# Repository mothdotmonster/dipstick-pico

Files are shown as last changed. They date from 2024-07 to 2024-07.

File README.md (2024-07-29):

# DIPSTICKpico

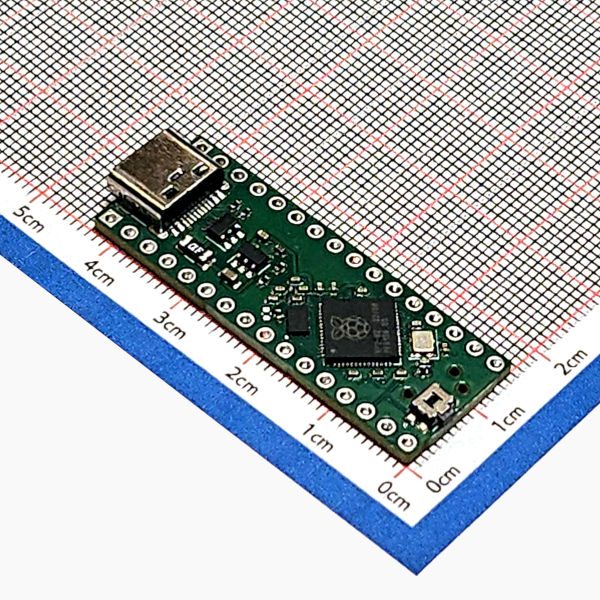
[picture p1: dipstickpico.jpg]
DIPSTICKpico on a familiar grid background


a smaller RP2040 board with USB-C.

[PRODUCTION FILES](https://github.com/mothdotmonster/dipstick-pico/releases/latest)

based off [RPcube](https://github.com/diminDDL/rpcube)  
uses [Paw-Connect](https://github.com/LeoDJ/Paw-Connect)

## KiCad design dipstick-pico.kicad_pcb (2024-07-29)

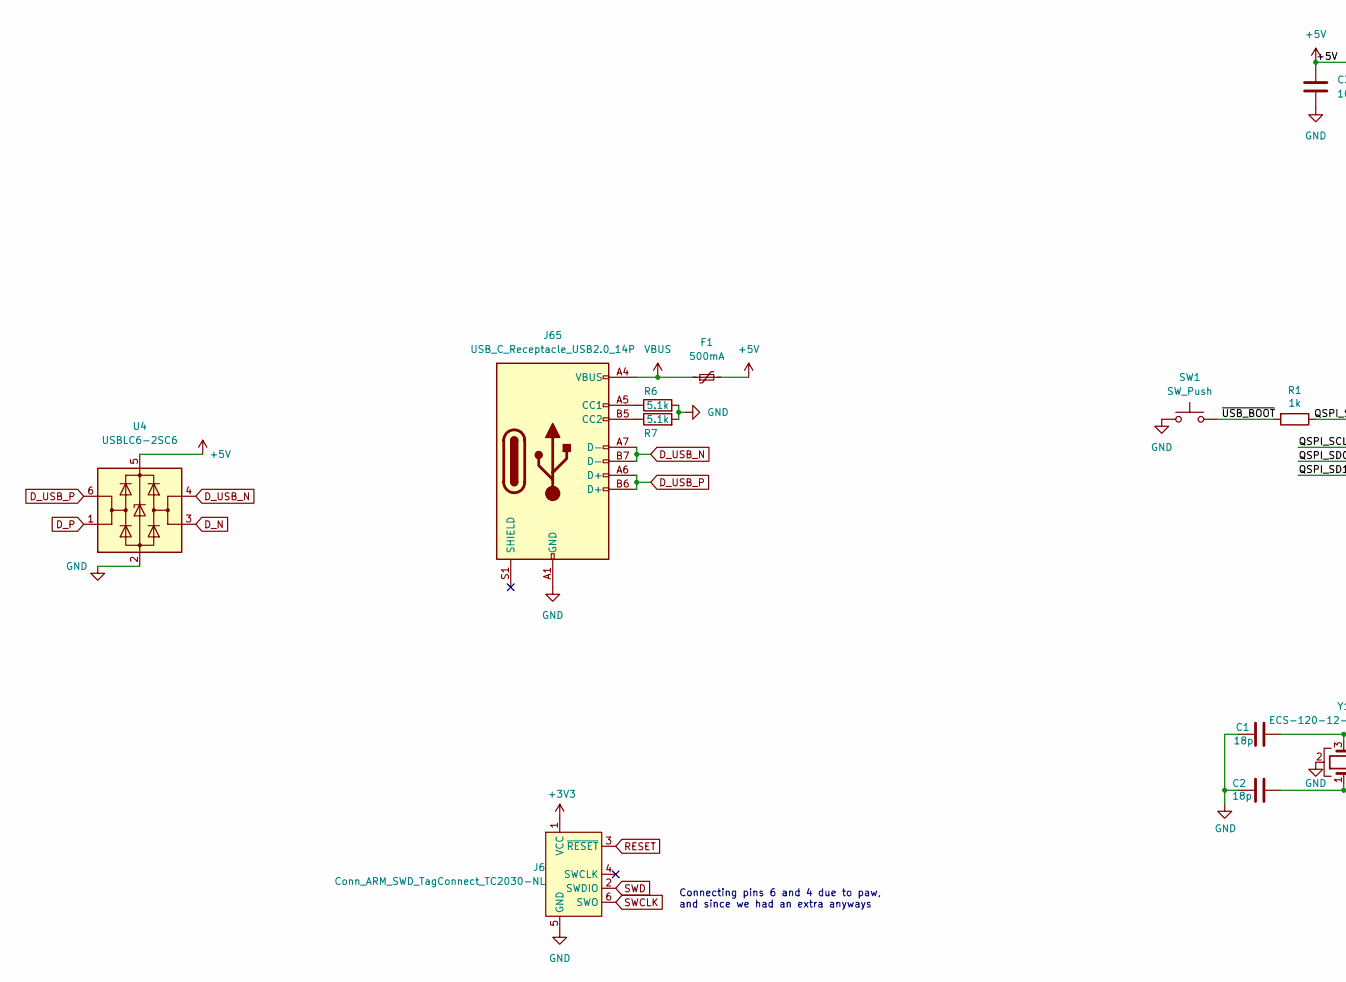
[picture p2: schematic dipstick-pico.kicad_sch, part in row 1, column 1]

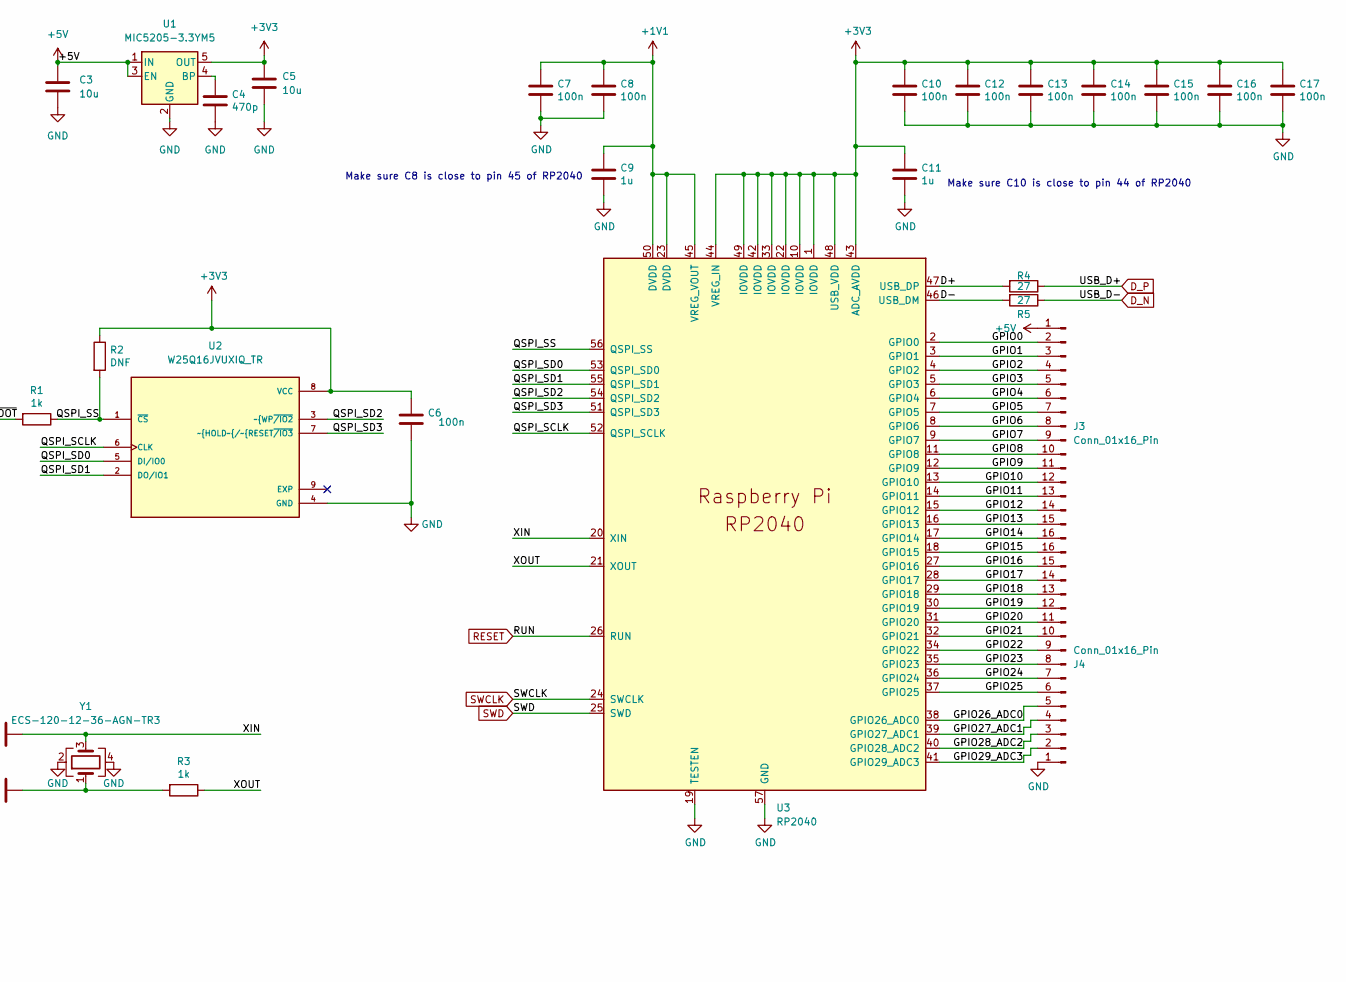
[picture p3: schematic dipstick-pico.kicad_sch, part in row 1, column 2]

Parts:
C1, C2: 18p; C_0402_1005Metric; LCSC C1549
C3: 10u; C_0603_1608Metric; LCSC C19702
C4: 470p; C_0402_1005Metric; LCSC C52923
C5: 10u; C_0402_1005Metric; LCSC C15525
C6, C7, C8, C10, C12, C13, C14, C15, C16, C17: 100n; C_0402_1005Metric; LCSC C1525
C9, C11: 1u; C_0402_1005Metric; LCSC C52923
F1: 500mA; Fuse_1206_3216Metric; LCSC C70076
J3, J4: Conn_01x16_Pin; PinHeader_1x16_P2.54mm_Vertical
J6: Conn_ARM_SWD_TagConnect_TC2030-NL; Tag-Connect_TC2030-IDC-NL_2x03_P1.27mm_Vertical
J65: USB_C_Receptacle_USB2.0_14P; USB_C_Receptacle_HRO_TYPE-C-31-M-12; LCSC C165948
R1, R3: 1k; R_0402_1005Metric; LCSC C11702
R2: DNF; R_0402_1005Metric
R4, R5: 27; R_0402_1005Metric; LCSC C25092
R6, R7: 5.1k; R_0402_1005Metric; LCSC C25905
SW1: SW_Push; SW_EVQ-P7A01P; LCSC C79167
U1: MIC5205-3.3YM5; SOT-23-5; LCSC C37970
U2: W25Q16JVUXIQ_TR; IC_W25Q16JVUXIQ_TR; PARTREV H; LCSC C2843335
U3: RP2040; RP2040-QFN-56; LCSC C2040
U4: USBLC6-2SC6; SOT-23-6; LCSC C2827654
Y1: ECS-120-12-36-AGN-TR3; Crystal_SMD_2520-4Pin_2.5x2.0mm; LCSC C479184

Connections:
+1V1: C7.1, C8.1, C9.1, U3.23 (DVDD), U3.45 (VREG_VOUT), U3.50 (DVDD)
+3V3: C5.1, C6.1, C10.1, C11.1, C12.1, C13.1, C14.1, C15.1, C16.1, C17.1, J6.1 (VCC), R2.1, U1.5 (OUT), U2.8 (VCC), U3.1 (IOVDD), U3.10 (IOVDD), U3.22 (IOVDD), U3.33 (IOVDD), U3.42 (IOVDD), U3.43 (ADC_AVDD), U3.44 (VREG_IN), U3.48 (USB_VDD), U3.49 (IOVDD)
+5V: C3.1, F1.2, J3.1, U1.1 (IN), U1.3 (EN), U4.5 (VBUS)
/D+: R4.2, U3.47 (USB_DP)
/D-: R5.2, U3.46 (USB_DM)
/GPIO0: J3.2, U3.2 (GPIO0)
/GPIO1: J3.3, U3.3 (GPIO1)
/GPIO2: J3.4, U3.4 (GPIO2)
/GPIO3: J3.5, U3.5 (GPIO3)
/GPIO4: J3.6, U3.6 (GPIO4)
/GPIO5: J3.7, U3.7 (GPIO5)
/GPIO6: J3.8, U3.8 (GPIO6)
/GPIO7: J3.9, U3.9 (GPIO7)
/GPIO8: J3.10, U3.11 (GPIO8)
/GPIO9: J3.11, U3.12 (GPIO9)
/GPIO10: J3.12, U3.13 (GPIO10)
/GPIO11: J3.13, U3.14 (GPIO11)
/GPIO12: J3.14, U3.15 (GPIO12)
/GPIO13: J3.15, U3.16 (GPIO13)
/GPIO14: J3.16, U3.17 (GPIO14)
/GPIO15: J4.16, U3.18 (GPIO15)
/GPIO16: J4.15, U3.27 (GPIO16)
/GPIO17: J4.14, U3.28 (GPIO17)
/GPIO18: J4.13, U3.29 (GPIO18)
/GPIO19: J4.12, U3.30 (GPIO19)
/GPIO20: J4.11, U3.31 (GPIO20)
/GPIO21: J4.10, U3.32 (GPIO21)
/GPIO22: J4.9, U3.34 (GPIO22)
/GPIO23: J4.8, U3.35 (GPIO23)
/GPIO24: J4.7, U3.36 (GPIO24)
/GPIO25: J4.6, U3.37 (GPIO25)
/GPIO26_ADC0: J4.5, U3.38 (GPIO26_ADC0)
/GPIO27_ADC1: J4.4, U3.39 (GPIO27_ADC1)
/GPIO28_ADC2: J4.3, U3.40 (GPIO28_ADC2)
/GPIO29_ADC3: J4.2, U3.41 (GPIO29_ADC3)
/QSPI_SCLK: U2.6 (CLK), U3.52 (QSPI_SCLK)
/QSPI_SD0: U2.5 (DI/IO0), U3.53 (QSPI_SD0)
/QSPI_SD1: U2.2 (DO/IO1), U3.55 (QSPI_SD1)
/QSPI_SD2: U2.3 (~WP~{/IO2), U3.54 (QSPI_SD2)
/QSPI_SD3: U2.7 (~HOLD~{/~{RESET~{/IO3), U3.51 (QSPI_SD3)
/QSPI_SS: R1.1, R2.2, U2.1 (~CS), U3.56 (QSPI_SS)
/XIN: C1.1, U3.20 (XIN), Y1.3
/XOUT: R3.1, U3.21 (XOUT)
/~USB_BOOT: R1.2, SW1.1_1, SW1.2
D_N: R5.1, U4.3 (I/O2)
D_P: R4.1, U4.1 (I/O1)
D_USB_N: J65.A7 (D-), J65.B7 (D-), U4.4 (I/O2)
D_USB_P: J65.A6 (D+), J65.B6 (D+), U4.6 (I/O1)
GND: C1.2, C2.2, C3.2, C4.2, C5.2, C6.2, C7.2, C8.2, C9.2, C10.2, C11.2, C12.2, C13.2, C14.2, C15.2, C16.2, C17.2, J4.1, J6.5 (GND), J65.A1 (GND), J65.A12 (GND), J65.B1 (GND), J65.B12 (GND), R6.2, R7.2, SW1.1, SW1.2_1, SW1.2_2, U1.2 (GND), U2.4 (GND), U3.19 (TESTEN), U3.57 (GND), U4.2 (GND), Y1.2, Y1.4
unnamed: C2.1, R3.2, Y1.1
unnamed: J65.A5 (CC1), R6.1
unnamed: J65.B5 (CC2), R7.1
unnamed: C4.1, U1.4 (BP)
RESET: J6.3 (~RESET), U3.26 (RUN)
SWCLK: J6.6 (SWO), U3.24 (SWCLK)
SWD: J6.2 (SWDIO), U3.25 (SWD)
VBUS: F1.1, J65.A4 (VBUS), J65.A9 (VBUS), J65.B4 (VBUS), J65.B9 (VBUS)

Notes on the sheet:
Make sure C10 is close to pin 44 of RP2040
Connecting pins 6 and 4 due to paw, and since we had an extra anyways
Make sure C8 is close to pin 45 of RP2040

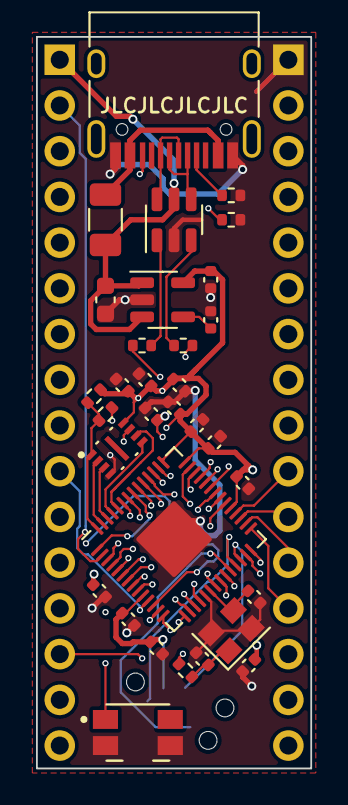
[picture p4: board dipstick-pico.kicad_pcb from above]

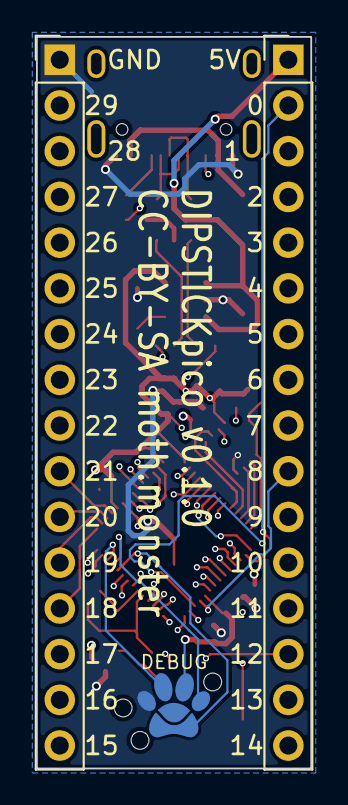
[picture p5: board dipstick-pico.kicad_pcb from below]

Board: 4 copper layers, 15.2 x 40.6 mm, 35 parts (3 on the bottom side), 57 nets.

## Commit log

2024-07-29 add readme and stuff
    [rpcube.kicad_pcb]
2024-07-29 forgot to rename those somehow
    [dipstick-pico.kicad_pcb, dipstick-pico.kicad_sch]

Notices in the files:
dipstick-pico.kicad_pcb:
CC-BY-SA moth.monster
